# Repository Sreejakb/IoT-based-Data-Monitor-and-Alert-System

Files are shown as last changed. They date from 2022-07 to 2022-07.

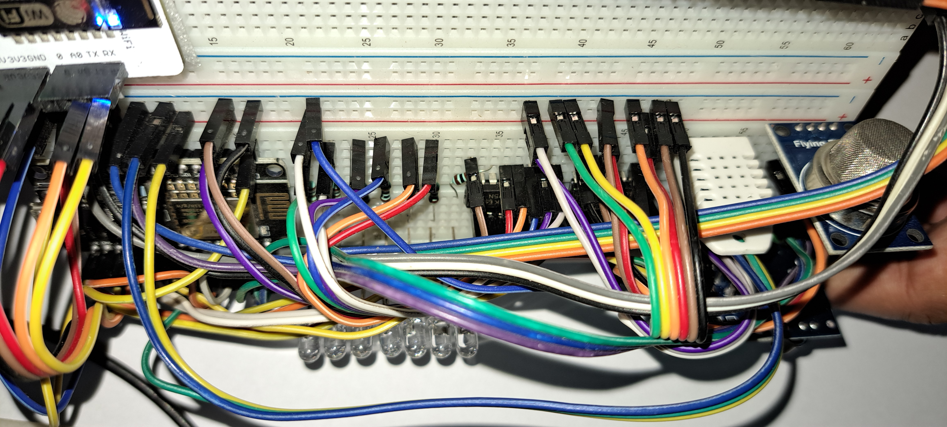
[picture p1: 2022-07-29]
Circuit Diagram/C4.jpg

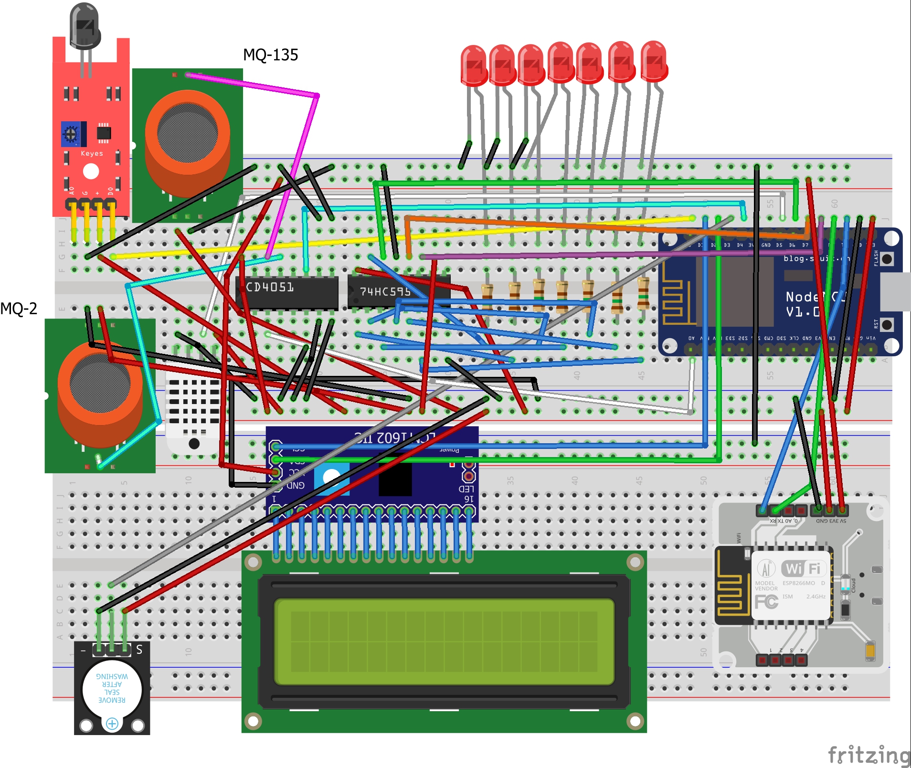
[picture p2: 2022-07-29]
Circuit Diagram/Data Monitor and Alert System.jpg

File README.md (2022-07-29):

# IoT-based-Data-Monitor-and-Alert-System
Monitor the Temperature, Humidity, Air Quality, LPG, Carbon Monoxide, Smoke and detect Fire in the surrounding environment. It can send alert to Telegram based on the limit set in the telegram app using telegram bot. Telegram app can also be used to monitor the values and download the CSV File from the Bolt IoT Cloud using the date and time entered by the user. The data can be monitored and visualized on the Bolt IoT Cloud Platform. Web Server can also be used to monitor and change the threshold values of the parameters.

<b><h3>Things used in this project</b></h3>

<h4><b>Hardware components</h4></b>

Bolt WiFi Module

ESP8266 development board

DHT-22 Sensor

MQ-135 Sensor

MQ-2 Sensor

Flame/Fire Sensor

20×4 LCD with I2C module

7 Red LEDS

150 Ohm Resistors – 7

Active Buzzer Module

CD4051 Single 8-channel Multiplexer/Demultiplexer IC

74HC595 8-bit Serial to Parallel Shift Register IC

Breadboard

Jumper Wires

<h4><b>Software, Apps and online services</h4></b>

Arduino IDE, Telegram Messaging App, Web Browser, Bolt IoT Cloud

<h4><b>Hardware setup</h4></b>

Step 1) Connect the DHT-22 Temperature and Humidity Sensor with the NodeMCU ESP8266 and Bolt IoT Module as per the following:

Vcc (DHT-22) is connected to 3.3 V (Bolt IoT Module)

Gnd (DHT-22) is connected to Gnd (Bolt IoT Module)

Data (DHT-22) is connected to D5 (NodeMCU ESP8266)

Step 2) Connect the MQ-135 Air Quality Sensor with the NodeMCU ESP8266 and Bolt IoT Module as per the following:

Vcc (MQ-135) is connected to 3.3 V (Bolt IoT Module)

Gnd (MQ-135) is connected to Gnd (Bolt IoT Module)

A0 (MQ-135) is connected to Channel 1 (CD4051 IC)

Step 3) Connect the MQ-2 LPG, Carbon Monoxide and Smoke Sensor with the NodeMCU ESP8266 and Bolt IoT Module as per the following:

Vcc (MQ-2) is connected to 3.3 V (Bolt IoT Module)

Gnd (MQ-2) is connected to Gnd (Bolt IoT Module)

A0 (MQ-2) is connected to Channel 0 (CD4051 IC)

Step 4) Connect the Fire Sensor with the NodeMCU ESP8266 and Bolt IoT Module as per the following:

Vcc (Fire sensor) is connected to 3.3 V (Bolt IoT Module)

Gnd (Fire sensor) is connected to Gnd (Bolt IoT Module)

D0 (Fire sensor) is connected to D0 (NodeMCU ESP8266)

Step 5) Connect each 7 LEDs to 150 Ohm Resistor which are then connected QA, QB, QC, QD, QE, QF, QG of SN74HC595 IC.

Step 6) Connect the 20×4 LCD with I2C module with the NodeMCU ESP8266 and Bolt IoT Module as per the following:

Vcc (I2C Module) is connected to 5 V (Bolt IoT Module)

Gnd (I2C Module) is connected to Gnd (Bolt IoT Module)

SCL (I2C Module) is connected to D1 (NodeMCU ESP8266)

SDA (I2C Module) is connected to D2 (NodeMCU ESP8266)

Step 7) Connect the SN74HC595 IC with the NodeMCU ESP8266 and Bolt IoT Module as per the following:

Vcc (SN74HC595 IC) is connected to 3.3 V (Bolt IoT Module)

SRCLR’ (SN74HC595 IC) is connected to 3.3 V (Bolt IoT Module)

Gnd (SN74HC595 IC) is connected to Gnd (Bolt IoT Module)

OE’ (SN74HC595 IC) is connected to Gnd (Bolt IoT Module)

SER (SN74HC595 IC) is connected to D6 (NodeMCU ESP8266)

RCLK (SN74HC595 IC) is connected to D7 (NodeMCU ESP8266)

SRCLK (SN74HC595 IC) is connected to D8 (NodeMCU ESP8266)

Step 8) Connect the Buzzer with the NodeMCU ESP8266 and Bolt IoT Module as per the following:

Vcc (Buzzer) is connected to 3.3 V (Bolt IoT Module)

Gnd (Buzzer) is connected to Gnd (Bolt IoT Module)

I/O (Buzzer) is connected to D3 (NodeMCU ESP8266)

Step 9) Connect the CD4051 IC with the NodeMCU ESP8266 and Bolt IoT Module as per the following:

Vdd (CD4051 IC) is connected to 3.3 V (Bolt IoT Module)

Gnd, Input B, Input C, Inhibit, Vss, Vee (CD4051 IC) is connected to Gnd (Bolt IoT Module)

Common in/out (CD4051 IC) is connected to A0 (NodeMCU ESP8266)

Input A (CD4051 IC) is connected to D4 (NodeMCU ESP8266)

Step 10) Bolt IoT Module with NodeMCU ESP8266 as per the following:

5V (Bolt IoT Module) is connected to 5 V (LCD I2C Module)

3.3V(Bolt IoT Module) is connected to 3.3V (NodeMCU ESP8266)

Gnd (Bolt IoT Module) is connected to Gnd (NodeMCU ESP8266)

RX (Bolt IoT Module) is connected to TX (NodeMCU ESP8266)

TX (Bolt IoT Module) is connected to RX (NodeMCU ESP8266)

<b>Video link of explanation and demonstration:</b> https://youtu.be/ghqOxM6Xmek

<b>Before uploading the code, add the following libraries:</b>

boltiot-arduino-helper – https://github.com/Inventrom/boltiot-arduino-helper

DHT-sensor-library – https://github.com/adafruit/DHT-sensor-library.git

LiquidCrystal library – https://github.com/arduino-libraries/LiquidCrystal

MQ135 – https://github.com/Phoenix1747/MQ135.git

MQ-2 sensor library – https://github.com/labay11/MQ-2-sensor-library.git

Fastbot – https://github.com/GyverLibs/FastBot.git

ESPAsyncTCP – https://github.com/me-no-dev/ESPAsyncTCP.git

ESPAsyncWebServer – https://github.com/me-no-dev/ESPAsyncWebServer.git

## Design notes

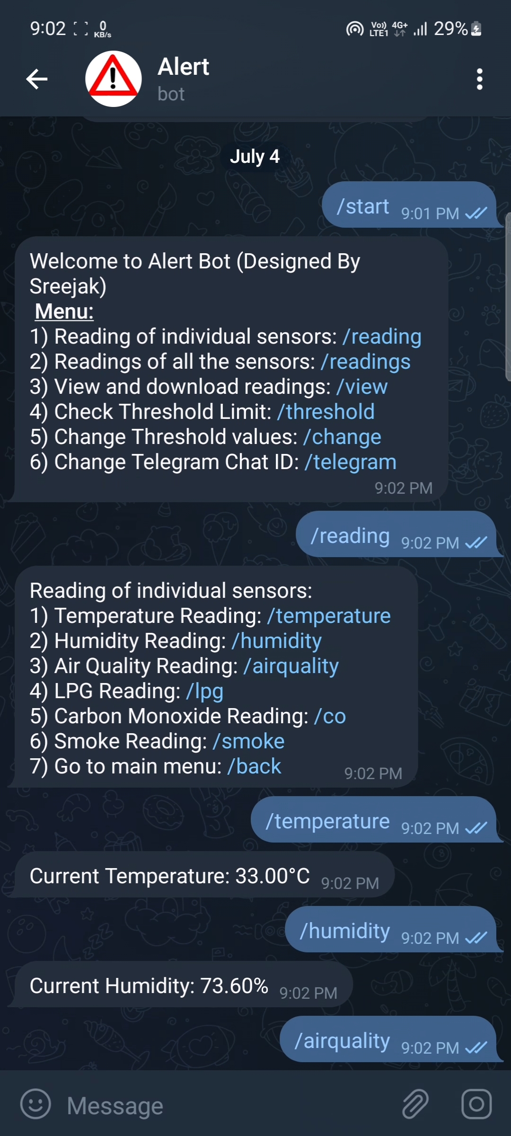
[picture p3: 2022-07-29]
Screenshot/S5.jpg

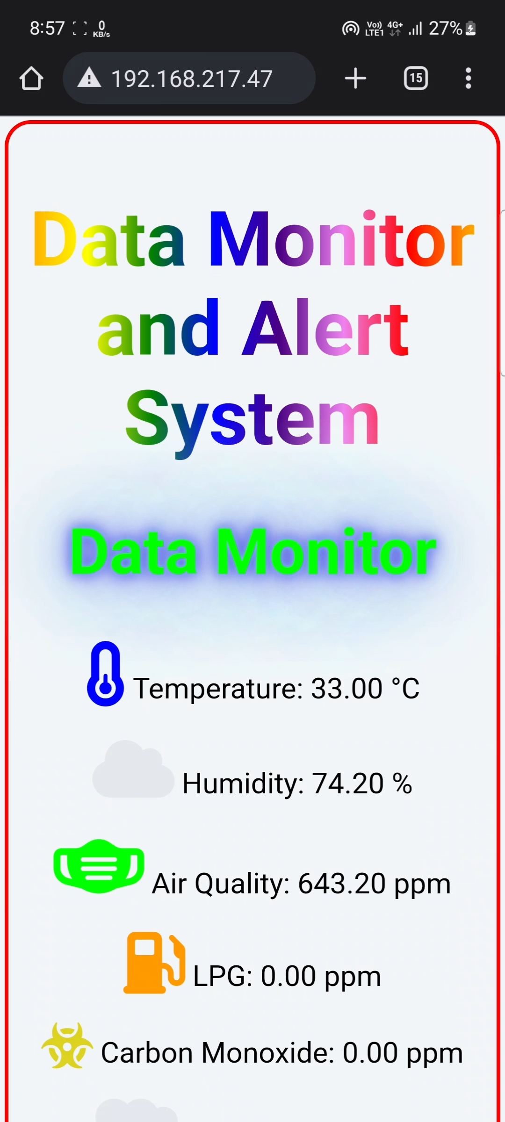
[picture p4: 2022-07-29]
Screenshot/S1.jpg

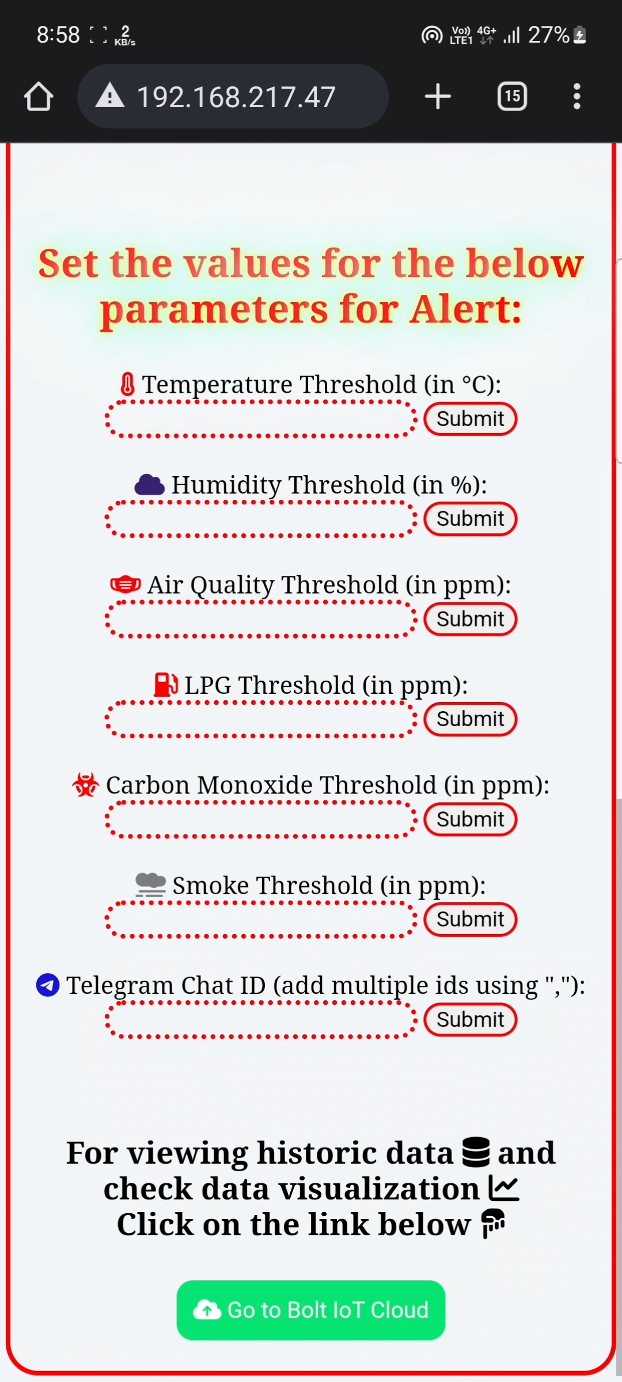
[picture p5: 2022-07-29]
Screenshot/S2.jpg

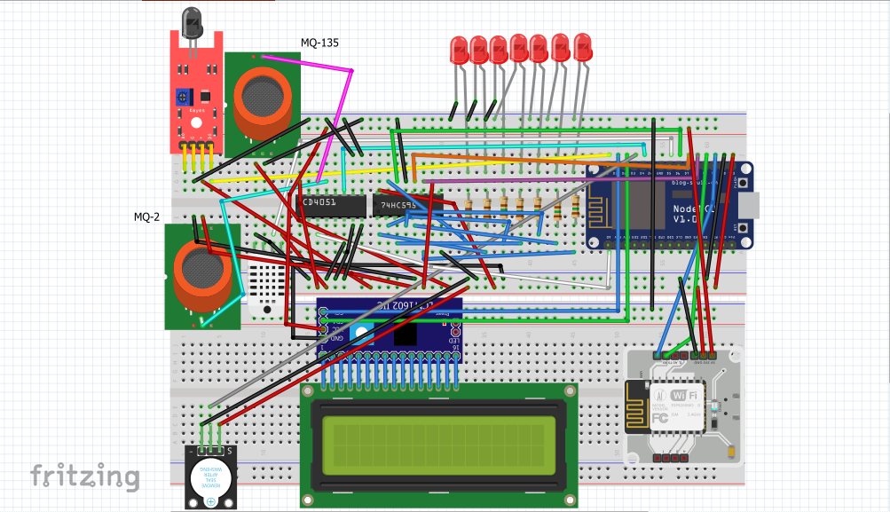
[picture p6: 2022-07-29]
Circuit Diagram/Data Monitor and Alert System_ss.png

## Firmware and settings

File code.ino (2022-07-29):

#include <boltiot.h>
#include <DHT.h>
#include <LCD_I2C.h>
#include <Wire.h>
#include <MQ135.h>
#include <MQ2.h>
#include <ESP8266WiFi.h>
#include <WiFiClientSecure.h>
#include <FastBot.h>
#include <ESPAsyncTCP.h>
#include <ESPAsyncWebServer.h>

#ifndef API_KEY
#define API_KEY "<Bolt IoT WiFi Module API Key>"
#endif
#ifndef DEVICE_ID
#define DEVICE_ID "<Bolt Device ID>"
#endif

#define DHTPIN 14
#define DHTTYPE DHT22
#define WIFI_SSID "<Wifi SSID>"
#define WIFI_PASS "<Wifi Password>"
#define BOT_TOKEN "<Telegram Bot Token>"
#define MUX_A D4 //Multiplexer Pin D4
#define flame D0
#define dataPin 12   //Outputs the byte to transfer
#define loadPin 13   //Controls the internal transference of data in SN74HC595 internal registers
#define clockPin 15  //Generates the clock signal to control the transference of data
#define Buzzer D3

int changeMux(int a) { // Function for Multiplexer
  digitalWrite(MUX_A, a);
  return A0;
}

LCD_I2C lcd(0x27, 20, 4);  // set the LCD address to 0x27 for a 20 chars and 4 line display
DHT dht(DHTPIN, DHTTYPE);
MQ135 mq135_sensor(changeMux(HIGH));
MQ2 mq2(changeMux(LOW));
WiFiClientSecure client;
FastBot bot(BOT_TOKEN); //Telegram bot

int f, T, H, A, L, C, S, FL, ftime, ttime, afh, afm, ath, atm;
int ch = 0;
float Temperature, Humidity, PPM, lpg, co, smoke;
String fl, readings, threshold, temperature, humidity, airquality, Lpg, carbon_monoxide, smk, webserver, wifi, r, link, details, fdate, fhr, fmn, tdate, thr, tmn, afhr, afmn, athr, atmn;
String tlimit = "40";  //Temperature Limit
String hlimit = "80"; //Humidity Limit
String alimit = "6000"; //Air Quality Limit
String llimit = "3"; //LPG Limit
String slimit = "5"; //Carbon Monoxide Limit
String climit = "5"; //Smoke Limit
String CHAT_ID = "<Your Telegram Chat ID>";
const char* PARAM_INPUT_1 = "t_limit";
const char* PARAM_INPUT_2 = "h_limit";
const char* PARAM_INPUT_3 = "a_limit";
const char* PARAM_INPUT_4 = "l_limit";
const char* PARAM_INPUT_5 = "c_limit";
const char* PARAM_INPUT_6 = "s_limit";
const char* PARAM_INPUT_7 = "ID";

String pushData(String *data) {  // Push data to Bolt IoT Cloud
  Temperature = dht.readTemperature();
  Humidity = dht.readHumidity();
  PPM = mq135_sensor.getCorrectedPPM(Temperature, Humidity);
  lpg = mq2.readLPG();
  co = mq2.readCO();
  smoke = mq2.readSmoke();
  return String(Temperature) + "," + String(Humidity) + "," + String(PPM) + "," + String(lpg) + "," + String(co) + "," + String(smoke);
}

// Webserver Code
const char index_html[] PROGMEM = R"rawliteral(
 <!DOCTYPE HTML>
  <html><head>
  <title>Data Monitor and Alert System</title>
  <meta name="viewport" content="width=device-width, initial-scale=1">
  <link rel="stylesheet" href="https://cdnjs.cloudflare.com/ajax/libs/font-awesome/4.7.0/css/font-awesome.min.css"> 
  <link rel="stylesheet" href="https://cdnjs.cloudflare.com/ajax/libs/font-awesome/6.0.0/css/all.min.css" integrity="sha512-9usAa10IRO0HhonpyAIVpjrylPvoDwiPUiKdWk5t3PyolY1cOd4DSE0Ga+ri4AuTroPR5aQvXU9xC6qOPnzFeg==" crossorigin="anonymous" referrerpolicy="no-referrer">   
  <link rel="stylesheet" href="https://unpkg.com/aos@next/dist/aos.css" />
  <link rel="stylesheet" href="https://cdnjs.cloudflare.com/ajax/libs/font-awesome/4.7.0/css/font-awesome.min.css">
  <style>
  body {
   background: #f1f5f7;
   text-align: center;
  }
  .rainbow {
  font-family:arial black;
  background-image: 
    linear-gradient(to right, red,orange,yellow,green,blue,indigo,violet, red); 
  -webkit-background-clip: text;
    -webkit-text-fill-color: transparent;  
  animation: fade 1000ms ease-in-out forwards , rainbow-animation 45s linear infinite;  
  }
  @keyframes rainbow-animation {
    to {
        background-position: 4500vh;
    }
  }
   .shadow {
  text-shadow:
    0 0 5px #ff0,
    0 0 10px #d9f4ff,
    0 0 20px #78ffbb,
    0 0 40px #d9fffb,
    0 0 80px #aae3f2,
    0 0 90px #bfe9f5,
    0 0 100px #d9f7ff,
    0 0 150px #fff;
  }
  .glowing {
      -webkit-animation: glowing 1.4s ease-in-out infinite alternate;
      -moz-animation: glowing 1.4s ease-in-out infinite alternate;
      animation: glowing 1.4s ease-in-out infinite alternate;
   }
   @-webkit-keyframes glowing{
      from {
         font-family:arial black;
  color: #00ff00;
  text-shadow:
    0 0 5px #4d048c,
    0 0 10px #060a7d,
    0 0 20px #3437e3,
    0 0 40px #5d5fe8,
    0 0 80px #5fb4ed,
    0 0 90px #77beed,
    0 0 100px #9bdaf2,
    0 0 150px #c1e6f5;
      }
      to {
    font-family:arial black;
    color: #00ff00;
    text-shadow:
    0 0 5px #83d4f7,
    0 0 10px #4346e0,
    0 0 20px #6769e6,
    0 0 40px #7879eb,
    0 0 80px #7ac1f0,
    0 0 90px #95cbf0,
    0 0 100px #aee0f2,
    0 0 150px #e1f1f7;
   }
  }
  .text-animation {
  opacity:0;
  }
  .text-animation span {
  top:50px;
  left:50px;
  opacity:0;
  animation:fade 400ms ease-in-out forwards;
  }
  @keyframes fade {
  0% {
    top:50px;
    left:50px;
    filter:blur(50px);
    opacity:0;
  }
  50% {
    filter:blur(10px);
    opacity:0.9;
  }
  100% {
    top:0px;
    left:0px;
    filter:blur(0px);
    opacity:1;
  }  
  }
  .border {
  border: 3px solid red;
  border-radius: 20px;
  padding: 15px;
  margin: 4px;
  }
  p{font-size:22px; font-family:arial black;}
  form{font-size:15px;}
  input[type="text"]
  {
    background: transparent;
    border: 3px dotted red;
    border-radius: 20px;
  }
  input[type="submit"]
  {
    border: 1.8px solid red;
    border-radius: 20px;
    outline:none;
  }
  .button {
  background-color: #07e371;
  border: none;
  color: white;
  padding: 10px 10px;
  text-align: center;
  display: inline-block;
  border-radius: 10px;
  font-size: 14px;
  margin: 4px 2px;
  cursor: pointer;
  -webkit-transition-duration: 0.2s; 
  transition-duration: 0.2s;
  }
  .button1:hover {
  box-shadow: 0 12px 16px 0 rgba(0,0,0,0.24), 0 17px 50px 0 rgba(0,0,0,0.19);
  border-radius: 12px;
  font-size: 16px;
   }
  </style>
   </head><body class="border">  
    <h1 class="rainbow" style="font-size:58px;" data-aos="zoom-in" data-aos-once="false" data-aos-delay="200">Data Monitor and Alert System </h1>
    <h2 class="glowing" style="font-size:48px;" data-aos="flip-down" data-aos-once="false" data-aos-duration="1500">Data Monitor</h2>
    <div data-aos="zoom-in" data-aos-offset="150" data-aos-once="false" data-aos-easing="ease-in-cubic">
    <p><i class="fa fa-thermometer-quarter" style="color:#0000ff;font-size:50px;"></i> Temperature: <span id="temp"> %TEMPERATURE% </span>&deg;C </p>
    <p><i class="fa fa-cloud" style="color: #e4e8ed;font-size:50px;"></i> Humidity: <span id="hum"> %HUMIDITY% </span>&#37</p>
    <p><i class="fa-solid fa-mask-face" style="color:#00ff00;font-size:55px;"></i> Air Quality: <span id="airq"> %AIRQ% </span> ppm </p>
    <p><i class="fas fa-gas-pump" style="color: #ff9900;font-size:47px;"></i> LPG: <span id="liq"> %LIQ% </span> ppm </p>
    <p><i class="fas fa-biohazard" style="color: #dbd221;font-size:35px;"></i> Carbon Monoxide: <span id="cbm"> %CBM% </span> ppm </p>
    <p><i class="fas fa-smog" style="color: #e4e8ed;font-size:50px;"></i> Smoke: <span id="smok"> %SMOK% </span> ppm </p>
    <p><i class="fa-solid fa-fire-flame-curved" style="color: red;font-size:47px;"></i> Fire: <span id="fla"> %FLA% </span> </p><br>
    </div>
    <h3 style="color:#ff0000;font-size:24px;" class="shadow , text-animation" data-aos="slide-right" data-aos-once="false" data-aos-duration="1200">Set the values for the below parameters for Alert:</h3>
    <form action="/get" data-aos="slide-left" data-aos-once="true">
    <i class="fa fa-thermometer-4" style="color: red"></i> Temperature Threshold (in &deg;C): <input type="text" name="t_limit" maxlength="6" required="">
    <input type="submit" value="Submit">
    </form><br>
    <form action="/get" data-aos="slide-right" data-aos-once="true">
    <i class="fa fa-cloud" style="color: #372170"></i> Humidity Threshold (in %): <input type="text" name="h_limit" maxlength="6" required="">
    <input type="submit" value="Submit">
    </form><br>
    <form action="/get" data-aos="slide-left" data-aos-once="true">
    <i class="fa-solid fa-mask-face" style="color:#ff0000"></i> Air Quality Threshold (in ppm): <input type="text" name="a_limit" maxlength="8" required="">
    <input type="submit" value="Submit">
    </form><br>
    <form action="/get" data-aos="slide-right" data-aos-once="true">
    <i class="fas fa-gas-pump" style="color: #ff0000"></i> LPG Threshold (in ppm): <input type="text" name="l_limit" maxlength="5" required="">
    <input type="submit" value="Submit">
    </form><br>
    <form action="/get" data-aos="slide-left" data-aos-once="true">
    <i class="fas fa-biohazard" style="color: #ff0000"></i> Carbon Monoxide Threshold (in ppm): <input type="text" name="c_limit" maxlength="5" required="">
    <input type="submit" value="Submit"> 
    </form><br>
    <form action="/get" data-aos="slide-right" data-aos-once="true">
    <i class="fas fa-smog" style="color: #7c7c80"></i> Smoke Threshold (in ppm): <input type="text" name="s_limit" maxlength="5" required="">
    <input type="submit" value="Submit">
    </form><br>
    <form action="/get" data-aos="slide-left" data-aos-once="true">
    <i class="fa fa-telegram" style="color: #1811d6"></i> Telegram Chat ID (add multiple ids using ","): <input type="text" name="ID" required="">
    <input type="submit" value="Submit">
    </form><br><br>
    <h3 data-aos="slide-down" data-aos-once="false">For viewing historic data <i class="fa fa-database"></i> and check data visualization <i class="fa fa-line-chart"></i><br>
    Click on the link below <i class="fas fa-hand-point-down"></i> </h3>
    <a href="<Bolt IoT Cloud Link>"><button class="button button1"><i class="fa fa-cloud-upload"></i> Go to Bolt IoT Cloud</button></a>
    <script>
    setInterval(function () {
    var xhttp = new XMLHttpRequest();
    xhttp.onreadystatechange = function() {
    if (this.readyState == 4 && this.status == 200) {
      document.getElementById("temp").innerHTML = this.responseText;
    }
    };
    xhttp.open("GET", "/temp", true);
    xhttp.send();
    }, 2600 ) ;
   setInterval(function () {
   var xhttp = new XMLHttpRequest();
   xhttp.onreadystatechange = function() {
    if (this.readyState == 4 && this.status == 200) {
      document.getElementById("hum").innerHTML = this.responseText;
   }
   };
    xhttp.open("GET", "/hum", true);
    xhttp.send();
   }, 2400 ) ;
   setInterval(function () {
   var xhttp = new XMLHttpRequest();
   xhttp.onreadystatechange = function() {
    if (this.readyState == 4 && this.status == 200) {
      document.getElementById("airq").innerHTML = this.responseText;
   }
   };
    xhttp.open("GET", "/airq", true);
    xhttp.send();
   }, 2200 ) ;
   setInterval(function () {
   var xhttp = new XMLHttpRequest();
   xhttp.onreadystatechange = function() {
    if (this.readyState == 4 && this.status == 200) {
      document.getElementById("liq").innerHTML = this.responseText;
    }
   };
    xhttp.open("GET", "/liq", true);
    xhttp.send();
   }, 2000 ) ;
   setInterval(function () {
   var xhttp = new XMLHttpRequest();
   xhttp.onreadystatechange = function() {
    if (this.readyState == 4 && this.status == 200) {
      document.getElementById("cbm").innerHTML = this.responseText;
    }
   };
    xhttp.open("GET", "/cbm", true);
    xhttp.send();
   }, 1800 ) ;
   setInterval(function () {
   var xhttp = new XMLHttpRequest();
   xhttp.onreadystatechange = function() {
    if (this.readyState == 4 && this.status == 200) {
      document.getElementById("smok").innerHTML = this.responseText;
    }
    };
    xhttp.open("GET", "/smok", true);
    xhttp.send();
   }, 1600 ) ;
   setInterval(function () {
   var xhttp = new XMLHttpRequest();
   xhttp.onreadystatechange = function() {
    if (this.readyState == 4 && this.status == 200) {
      document.getElementById("fla").innerHTML = this.responseText;
    }
    };
    xhttp.open("GET", "/fla", true);
    xhttp.send();
    }, 1400 ) ;
   </script><script>
   var wrapper = document.getElementsByClassName("text-animation")[0];
   wrapper.style.opacity="1";
   wrapper.innerHTML = wrapper.textContent.replace(/./g,"<span>$&</span>");
   var spans = wrapper.getElementsByTagName("span");
   for(var i=0;i<spans.length;i++){
   spans[i].style.animationDelay = i*150+"ms";
   }  
   </script>
   <script src="https://unpkg.com/aos@next/dist/aos.js"></script>
   <script>
   AOS.init();
   </script></body></html>)rawliteral";

void notFound(AsyncWebServerRequest *request) {
  request->send(404, "text/plain", "Error 404: Not found on this webserver");
}

AsyncWebServer server(80);  

String processor(const String& var) {
  if (var == "TEMPERATURE") {
    return String(Temperature);
  }
  else if (var == "HUMIDITY") {
    return String(Humidity);
  }
  else if (var == "AIRQ") {
    return String(PPM);
  }
  else if (var == "LIQ") {
    return String(lpg);
  }
  else if (var == "CBM") {
    return String(co);
  }
  else if (var == "SMOK") {
    return String(smoke);
  }
  else if (var == "FLA") {
    return fl;
  }
  else if (var == "t_limit") {
    return tlimit;
  }
  else if (var == "h_limit") {
    return hlimit;
  }
  else if (var == "a_limit") {
    return alimit;
  }
  else if (var == "l_limit") {
    return llimit;
  }
  else if (var == "c_limit") {
    return climit;
  }
  else if (var == "s_limit") {
    return slimit;
  }
  else if (var == "ID") {
    return CHAT_ID;
  }
  return String();
}
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
void loop() {
  String tmes ="", hmes = "", ames = "", lmes = "", cmes = "", smes = "", fmes = "";
  bot.tick();
  boltiot.handleCommand();
  float* values = mq2.read(false);
  lpg = mq2.readLPG();
  co = mq2.readCO();
  smoke = mq2.readSmoke();
  Temperature = dht.readTemperature();
  Humidity = dht.readHumidity();
  PPM = mq135_sensor.getCorrectedPPM(Temperature, Humidity);
  f = digitalRead(flame);
  lcd.setCursor(0, 0);
  lcd.print("Temperature:");
  lcd.print(Temperature);
  lcd.print((char)223);
  lcd.print("C");
  lcd.setCursor(0, 1);
  lcd.print("Hmd:");
  lcd.print(int(Humidity));
  lcd.print("% ");
  lcd.print("AirQ:");
  lcd.print(int(PPM));
  lcd.print("ppm");
  lcd.setCursor(0, 2);
  lcd.print("LPG:");
  lcd.print(int(lpg));
  lcd.print("ppm ");
  lcd.print("CO:");
  lcd.print(co);
  lcd.print("ppm");
  lcd.setCursor(0, 3);
  lcd.print("Smk:");
  lcd.print(smoke);
  lcd.print("ppm ");
  lcd.print("Fire:");
  if (f == 1) {
    FL = 0;
    lcd.print("No");
    fl = "Not Detected";
  }
  else {
    FL = 1;
    lcd.print("Yes");
    fl = "Detected";
    fmes = "🔥<b>Fire</b>🔥 is dectected.\n";
  }
  readings = String("Current readings of all the sensors: \n1) Temperature: ") + Temperature + "°C \n2) Humidity: " + Humidity + "% \n3) Air Quality: " + PPM + " ppm \n4) LPG: " + lpg + " ppm \n5) Carbon Monoxide: " + co + " ppm \n6) Smoke: " + smoke + " ppm  \n7) Fire: " + fl;
  threshold = String("Current threshold of all the sensors: \n1) Temperature: ") + tlimit + "°C \n2) Humidity: " + hlimit + "% \n3) Air Quality: " + alimit + " ppm \n4) LPG: " + llimit + " ppm \n5) Carbon Monoxide: " + climit + " ppm \n6) Smoke: " + slimit + " ppm";
  temperature = String("Current Temperature: ") + Temperature + "°C";
  humidity = String("Current Humidity: ") + Humidity + "%";
  airquality = String("Current Air Quality: ") + PPM + " ppm";
  Lpg = String("Current LPG: ") + lpg + " ppm";
  carbon_monoxide = String("Current Carbon Monoxide: ") + co + " ppm";
  smk = String("Current Smoke: ") + smoke + " ppm";
  link = String("Click on the link to download: https://cloud.boltiot.com/downloadDataFromTable/Alert/<Bolt Wifi Module ID>?from=") + fdate + "+" + afhr + "%3A" + afmn + "&to=" + tdate + "+" + athr + "%3A" + atmn + "&duration=month";
  webserver = String("You can view real-time values and change the threshold values temporarily using the link (Connect to same access point of ESP8266): http://") + wifi ;
  fdate = details.substring(0,10);
  fhr = details.substring(11,13);
  fmn = details.substring(14,16);
  tdate = details.substring(17,27);
  thr = details.substring(28,30);
  tmn = details.substring(31,33);
  ftime = (60*fhr.toInt()+fmn.toInt())-330;
  ttime = (60*thr.toInt()+tmn.toInt())-330;
  afh = ftime/60;
  afm = ftime%60;
  ath = ttime/60;
  atm = ttime%60;
  if (afh<10) {
    afhr = "0" + String(afh);
  }
  else {
    afhr = String(afh);
  }
  if (ath<10) {
    athr = "0" + String(ath);
  }
  else {
    athr = String(ath);
  }
  if (afm<10) {
    afmn = "0" + String(afm);
  }
  else {
    afmn = String(afm);
  }
  if (atm<10) {
    atmn = "0" + String(atm);
  }
  else {
    atmn = String(atm);
  }
  if (Temperature <= tlimit.toFloat()) {
    T = 0;
  }
  else {
    T = 64;
    tmes = "🌡<b>Temperature</b>🌡 has crossed the threshold value of " + tlimit + "°C.\n";
}
  if (Humidity <= hlimit.toFloat()) {
    H = 0;
  }
  else {
    H = 32;
    hmes = "☁<b>Humidity</b>☁ has crossed the threshold value of " + hlimit + "%.\n";
}
  if (PPM <= alimit.toFloat()) {
    A = 0;
  }
  else {
    A = 16;
    ames = "😷<b>Air Quality</b>😷 has crossed the threshold value of " + alimit + " ppm.\n";
}
  if (lpg <= llimit.toFloat()) {
    L = 0;
  }
  else {
    L = 8;
    lmes = "⛽<b>Lpg</b>⛽ has crossed the threshold value of " + llimit + " ppm.\n";
}
  if (co <= climit.toFloat()) {
    C = 0;
  }
  else {
    C = 4;
    cmes = "🚬<b>Carbon Monoxide</b>🚬 has crossed the threshold value of " + climit + " ppm.\n";
}
  if (smoke <= slimit.toFloat()) {
    S = 0;
  }
  else {
    S = 2;
    smes = "💨<b>Smoke</b>💨 has crossed the threshold value of " + slimit + " ppm.\n";
}
  ch = T + H + A + L + C + S + FL;
  digitalWrite(loadPin, LOW);
  shiftOut(dataPin, clockPin, MSBFIRST, ch);
  digitalWrite(loadPin, HIGH);
  if (ch == 0) {
    noTone(Buzzer);  //No Sound from buzzer
  }
  else {
    tone(Buzzer, (ch * 80) + 250);  //change buzzer sound according to the Alert Number
    lcd.clear();
    lcd.setCursor(0, 0);
    lcd.print("Sending Alert No." + String(ch));
    lcd.setCursor(0, 1);
    lcd.print("to Telegram Chat ID: ");
    lcd.setCursor(0, 2);
    lcd.print(CHAT_ID);
    // Sending Telegram Message
    bot.sendMessage("⚠<b><u>Alert No." + String(ch) + "</u></b>⚠\n" + tmes + hmes + ames + lmes + cmes + smes + fmes + readings + "\nImmediate action is required.");
    delay(2000);
    lcd.clear();
  }
  delay(1400);
}
